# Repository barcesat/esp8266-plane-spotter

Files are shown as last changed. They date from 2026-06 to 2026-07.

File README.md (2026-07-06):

# ✈️ ESP8266 Plane Spotter

A desktop gadget with a **tactical / military-style** interface that shows the
**aircraft currently flying closest to your home** on a 0.96" OLED, plus live
weather, an NTP clock and a bunch of nerdy stats. Live ADS-B data comes from
the [OpenSky Network](https://opensky-network.org/) API; weather from
[Open-Meteo](https://open-meteo.com/); routes/airlines from
[hexdb.io](https://hexdb.io/). 3D-printable desktop case included in
[`hardware/`](hardware/).

Default home location is the **centre of Pinerolo (TO), Italy** — change it in
`config.h` to point at your own roof.

<p align="center">
  Plane Spotter desktop gadget showing the radar screen
</p>

<p align="center"><em>The finished gadget in its 3D-printed case, showing the RADAR screen.</em></p>

---

## What it shows

Every screen has a tactical header: title + page index on the left, a live NTP
clock on the right. It cycles through five screens every 7 seconds:

1. **TARGET** — nearest aircraft: callsign, a type icon, distance + compass
   bearing, altitude (m and flight level), a heading arrow, ground speed and a
   vertical altitude gauge.
2. **INTEL** — callsign, **airline**, **departure → arrival** route and an
   **ETA** estimate (looked up from hexdb.io), plus ICAO24 and heading.
3. **RADAR** — North-up PPI: home at the centre, range rings (outer = 120 km),
   a rotating sweep and a blip per aircraft. Blips are **dead-reckoned** from
   track + speed so they creep in real time between refreshes, with radar
   **persistence** (bright as the sweep passes, then a faint dot). The nearest
   is boxed; a tick marks the wall direction. Side panel: type, callsign, RNG,
   BRG, contact count.
4. **WX** — current weather (temperature, condition icon, humidity, wind) and a
   minimal next-hours forecast strip.
5. **SYSTEM** — big `HH:MM:SS` clock with live milliseconds, date, uptime,
   target count, WiFi signal bars, free RAM and request counters.

The **type icon** uses the OpenSky emitter category (`extended=1`) when present;
since that is often unset, the firmware otherwise estimates the type from
altitude + speed and flags it with a leading `~`.

Aircraft data refreshes every 60 s, weather every 10 min (both configurable —
see the rate-limit note below).

---

## Hardware

| Part | Notes |
|---|---|
| ESP8266 board | NodeMCU v2/v3, Wemos D1 mini, or similar |
| 0.96" OLED, **SSD1306** | either the 7-pin **4-wire SPI** module (`GND VCC SCK SDA RES DC CS`) or the 4-pin **I2C** module (`GND VCC SCL SDA`) |

### Wiring

Both SSD1306 module types are supported — set `OLED_USE_I2C` in `config.h` to
match yours (`false` = SPI, `true` = I2C).

**4-wire SPI module** (`OLED_USE_I2C false`): hardware SPI is used, so `SCK`
and `SDA` are fixed; the other three pins are configurable in `config.h`.

| OLED pin | ESP8266 (NodeMCU label / GPIO) | Role |
|---|---|---|
| GND | GND | Ground |
| VCC | 3V3 | Power |
| SCK | **D5 / GPIO14** | HW SPI clock (fixed) |
| SDA | **D7 / GPIO13** | HW SPI data / MOSI (fixed) |
| RES | D0 / GPIO16 | Reset |
| DC  | D2 / GPIO4  | Data/Command |
| CS  | D1 / GPIO5  | Chip select |

**I2C module** (`OLED_USE_I2C true`): hardware I2C on the ESP8266's standard
I2C pins; both are configurable in `config.h`.

| OLED pin | ESP8266 (NodeMCU label / GPIO) | Role |
|---|---|---|
| GND | GND | Ground |
| VCC | 3V3 | Power |
| SCL | **D1 / GPIO5** | I2C clock |
| SDA | **D2 / GPIO4** | I2C data |

> The default pins avoid the ESP8266 boot-strapping pins (GPIO0/2/15), so the
> board flashes and boots reliably. Most I2C SSD1306 modules use address
> `0x3C` (U8g2's default); if yours is `0x3D`, add
> `u8g2.setI2CAddress(0x3D * 2);` before `u8g2.begin()`.

**Wiring Schema**
```
        ESP8266 (NodeMCU)                OLED SSD1306 SPI
      ┌───────────────────┐            ┌──────────────────┐
      │ 3V3 ──────────────┼────────────┤ VCC              │
      │ GND ──────────────┼────────────┤ GND              │
      │ D5/GPIO14 ────────┼────────────┤ SCK              │
      │ D7/GPIO13 ────────┼────────────┤ SDA (MOSI)       │
      │ D0/GPIO16 ────────┼────────────┤ RES              │
      │ D2/GPIO4  ────────┼────────────┤ DC               │
      │ D1/GPIO5  ────────┼────────────┤ CS               │
      └───────────────────┘            └──────────────────┘

        ESP8266 (NodeMCU)                OLED SSD1306 I2C
      ┌───────────────────┐            ┌──────────────────┐
      │ 3V3 ──────────────┼────────────┤ VCC              │
      │ GND ──────────────┼────────────┤ GND              │
      │ D1/GPIO5  ────────┼────────────┤ SCL              │
      │ D2/GPIO4  ────────┼────────────┤ SDA              │
      └───────────────────┘            └──────────────────┘
```

### 3D-printed case

A simple two-part desktop case lives in [`hardware/`](hardware/):

| File | Part |
|---|---|
| [`hardware/Radar1.stl`](hardware/Radar1.stl) | Case part 1 |
| [`hardware/radar2.stl`](hardware/radar2.stl) | Case part 2 |

<p align="center">
  CAD render of the 3D-printed case
</p>

Print both, slot the board + OLED inside, and stand it on your desk. It is
designed to hang on a wall facing a known compass heading — set that heading in
`WALL_HEADING_DEG` so the radar's wall tick lines up.

---

## Build & flash

### Option A — Arduino IDE

1. Install the **ESP8266 board package** (Boards Manager → "esp8266").
2. Install libraries via **Library Manager**:
   - `U8g2` by olikraus
   - `ArduinoJson` by Benoit Blanchon (v7.x)
3. Copy `firmware/plane_spotter/config.example.h` → `config.h` and fill in your
   WiFi credentials (and your coordinates, if not Pinerolo).
4. Open `firmware/plane_spotter/plane_spotter.ino`, select your board, and
   upload.

### Option B — PlatformIO

```bash
cd firmware
# copy and edit the config first:
cp plane_spotter/config.example.h plane_spotter/config.h
pio run -t upload
pio device monitor
```

`platformio.ini` already pins the board, libraries, and 115200 monitor speed.

---

## Configuration

All settings live in `config.h` (git-ignored so your WiFi password stays
private). Key options:

| Define | Meaning |
|---|---|
| `WIFI_SSID` / `WIFI_PASS` | Your network |
| `OLED_USE_I2C` | Display module type: `false` = 4-wire SPI (7-pin), `true` = I2C (4-pin) |
| `HOME_LAT` / `HOME_LON` | Your home coordinates (default: Pinerolo) |
| `SEARCH_RADIUS_DEG` | Half-size of the sky box to query (~1.0° ≈ 111 km) |
| `UPDATE_INTERVAL_MS` | Poll period for OpenSky |
| `INCLUDE_ON_GROUND` | Include parked/taxiing aircraft; set `false` near airports |
| `WALL_HEADING_DEG` | Compass heading the wall/device faces (used by the radar wall tick) |
| `TIMEZONE` | POSIX timezone string for the NTP clock (default: Europe/Rome) |
| `WEATHER_INTERVAL_MS` | Weather refresh period (default: 10 min) |
| `OPENSKY_CLIENT_ID` / `OPENSKY_CLIENT_SECRET` | Optional OpenSky OAuth2 client for a much bigger budget |

### Data sources

| What | Service | Key needed |
|---|---|---|
| Aircraft (ADS-B) | OpenSky Network | optional (OAuth2 client → bigger quota) |
| Weather + forecast | Open-Meteo | no |
| Airline / route / ETA | hexdb.io | no |
| Clock | NTP (`pool.ntp.org`) | no |

> Route/ETA come from a community database, so they aren't available for every
> flight — `INTEL` shows `unknown` / `ETA --` when a route isn't found.

---

## Notes on the OpenSky API

- Anonymous access has a **small daily request budget (~400 calls)**, shared
  per public IP. Polling every 60 s is ~1440 calls/day, so anonymously you
  *will* hit `HTTP 429 Too many requests` and the display freezes on the last
  data (the firmware keeps showing the last known aircraft when rate-limited).
- **Recommended: use an OpenSky account.** Create one, go to *Account → API
  clients*, create a client, and put the `clientId`/`clientSecret` into
  `OPENSKY_CLIENT_ID`/`OPENSKY_CLIENT_SECRET`. The firmware then does the OAuth2
  `client_credentials` flow (token from `auth.opensky-network.org`, sent as a
  `Bearer` header, auto-refreshed) and gets a far larger quota — 60 s polling
  works comfortably. Anonymous (no client) still works if you raise
  `UPDATE_INTERVAL_MS` to ~300000 (5 min).
- **Aircraft-type icons:** OpenSky's emitter category (state index 17, via
  `extended=1`) is frequently `0` (unknown) in practice, so when it is missing
  the firmware estimates the type from altitude + speed and flags it with a
  leading `~` (e.g. `~Small`). Real category data, when present, is used as-is.
- Coverage is community ADS-B, so very low / very local traffic may not always
  appear. A larger `SEARCH_RADIUS_DEG` finds more planes but uses more RAM to
  parse (the ESP8266 only has ~40 KB free heap, so don't go wild).
- TLS certificate validation is skipped (`setInsecure()`) to keep memory low;
  fine for read-only public data.

---

## License

MIT — see [LICENSE](LICENSE).

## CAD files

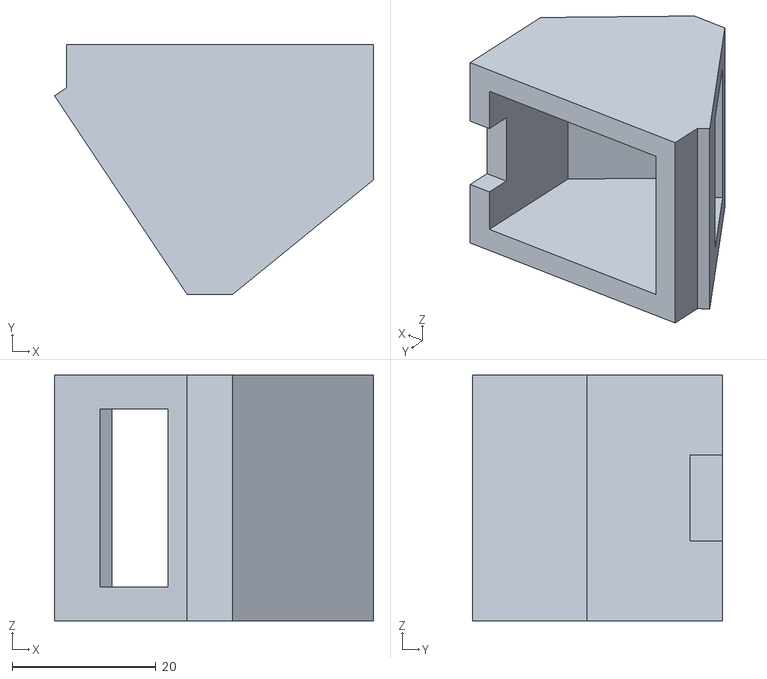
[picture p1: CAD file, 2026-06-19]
hardware/Radar1.stl
44.4 x 34.7 x 34.2

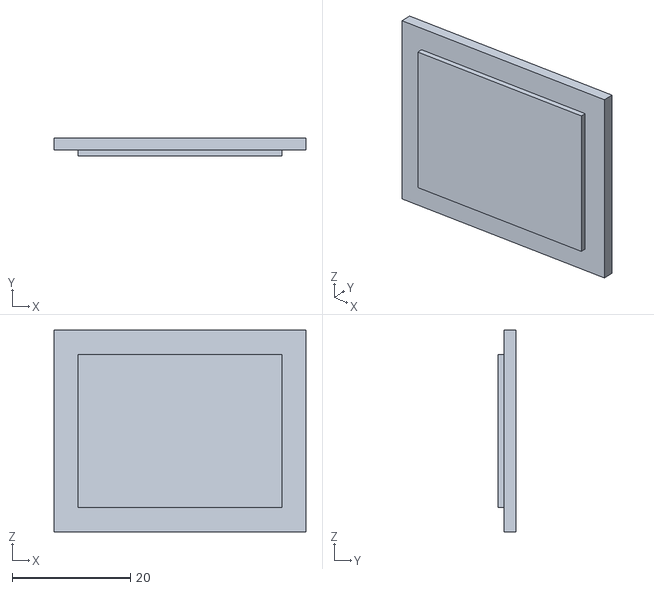
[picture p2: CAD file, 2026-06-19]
hardware/radar2.stl
42.7 x 3.00 x 34.2

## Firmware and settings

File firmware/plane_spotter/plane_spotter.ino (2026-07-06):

/*
 * ESP8266 Plane Spotter
 * --------------------------------------------------------------------------
 * Shows the aircraft currently flying closest to your home on a 0.96" SSD1306
 * OLED, plus a bunch of nerdy statistics. Live ADS-B data is pulled from
 * the free OpenSky Network REST API.
 *
 * Board   : any ESP8266 (NodeMCU v2/v3, Wemos D1 mini, ...)
 * Display : 0.96" OLED, SSD1306 128x64, either
 *           - 4-wire SPI (7 pins: GND, VCC, SCK, SDA, RES, DC, CS), or
 *           - I2C (4 pins: GND, VCC, SCL, SDA)
 *           Pick with OLED_USE_I2C in config.h.
 *
 * Wiring (defaults, see README for the full tables):
 *   SPI OLED  ESP8266                    I2C OLED  ESP8266
 *   GND  -->  GND                        GND  -->  GND
 *   VCC  -->  3V3                        VCC  -->  3V3
 *   SCK  -->  D5 / GPIO14 (HW, fixed)    SCL  -->  D1 / GPIO5
 *   SDA  -->  D7 / GPIO13 (HW, fixed)    SDA  -->  D2 / GPIO4
 *   RES  -->  D0 / GPIO16
 *   DC   -->  D2 / GPIO4
 *   CS   -->  D1 / GPIO5
 *
 * Libraries (install from the Arduino Library Manager):
 *   - U8g2        by olikraus
 *   - ArduinoJson by Benoit Blanchon (v6.x)
 *
 * Copy config.example.h to config.h and fill in your details before flashing.
 */

#include <ESP8266WiFi.h>
#include <WiFiClientSecure.h>
#include <ESP8266HTTPClient.h>
#include <ArduinoJson.h>
#include <U8g2lib.h>
#include <math.h>
#include <time.h>
#include <sys/time.h>

#include "config.h"

#ifndef INCLUDE_ON_GROUND
#define INCLUDE_ON_GROUND true
#endif

// ---------------------------------------------------------------------------
// Display: SSD1306 128x64, 4-wire hardware SPI or hardware I2C, selected by
// OLED_USE_I2C in config.h.
// SPI: HW SPI uses the fixed ESP8266 pins SCLK=GPIO14 (D5) and MOSI=GPIO13
//   (D7); only CS / DC / RESET are configurable.
// I2C: SCL/SDA pins come from config.h (defaults: SCL=GPIO5/D1, SDA=GPIO4/D2,
//   the ESP8266 standard I2C pins). Most modules answer at address 0x3C,
//   U8g2's default; if yours is 0x3D, add u8g2.setI2CAddress(0x3D * 2)
//   before begin().
// ---------------------------------------------------------------------------
#ifndef OLED_USE_I2C
#define OLED_USE_I2C false   // config.h files from before this switch are SPI
#endif

#if OLED_USE_I2C
U8G2_SSD1306_128X64_NONAME_F_HW_I2C u8g2(U8G2_R0, /* reset=*/ U8X8_PIN_NONE,
                                         /* clock=*/ PIN_OLED_SCL,
                                         /* data=*/  PIN_OLED_SDA);
#else
U8G2_SSD1306_128X64_NONAME_F_4W_HW_SPI u8g2(U8G2_R0, PIN_OLED_CS, PIN_OLED_DC,
                                            PIN_OLED_RST);
#endif

// ---------------------------------------------------------------------------
// Data model
// ---------------------------------------------------------------------------
struct Aircraft {
  char   icao24[8];
  char   callsign[10];
  char   country[24];
  double lat;
  double lon;
  float  altitudeM;   // geometric/barometric altitude in metres
  float  velocityMs;  // ground speed in m/s
  float  trackDeg;    // true track over ground (0 = north)
  float  vrateMs;     // vertical rate in m/s (+climb / -descent)
  bool   onGround;
  int    category;    // OpenSky emitter category (state index 17, 0 = unknown)
  double distanceKm;  // great-circle distance from home
  double bearingDeg;  // bearing from home to aircraft
  bool   valid;
};

Aircraft nearest;

// Per-aircraft state for the radar, including enough to dead-reckon (estimate)
// the position between data refreshes so the blips creep in real time.
struct Blip { double lat; double lon; float track; float speedMs; };
const uint8_t MAX_BLIPS = 20;
Blip     blips[MAX_BLIPS];
uint8_t  blipCount  = 0;
uint32_t lastDataMs = 0;   // millis() of the last successful aircraft fetch

// OpenSky OAuth2 bearer token (when client credentials are configured).
String   accessToken;
uint32_t tokenExpiryMs = 0;

// Current weather (from Open-Meteo).
struct Weather {
  float tempC;
  float windKmh;
  int   humidity;
  int   code;      // WMO weather code
  bool  valid = false;
} weather;
uint32_t lastWeatherPoll = 0;

// Short hourly forecast (a few hours ahead).
struct Fcast { int hour; float tempC; int code; };
const uint8_t FC_N = 3;
Fcast   fcast[FC_N];
uint8_t fcCount = 0;

// Route / airline / ETA for the current nearest aircraft (from hexdb.io).
struct RouteInfo {
  char   callsign[10];   // which callsign this data is for
  char   airline[18];
  char   dep[6];
  char   arr[6];
  bool   haveRoute;
  bool   haveArrPos;
  double arrLat, arrLon;
} routeInfo;

// Runtime statistics (the nerdy bit)
struct Stats {
  uint32_t requestsOk   = 0;
  uint32_t requestsFail = 0;
  uint16_t inView       = 0;   // aircraft inside the search box on last poll
  uint16_t maxInView    = 0;   // session record
  double   closestEver  = 1e9; // closest distance seen this session (km)
  uint32_t lastUpdateMs = 0;
} stats;

uint8_t  screen           = 0;         // which screen is showing
uint32_t lastScreenSwap   = 0;
uint32_t lastPoll         = 0;
bool     firstFetchDone   = false;
bool     firstWeatherDone = false;

const uint8_t  NUM_SCREENS    = 5;
const uint32_t SCREEN_SWAP_MS = 7000;

// ---------------------------------------------------------------------------
// Geo helpers
// ---------------------------------------------------------------------------
static double deg2rad(double d) { return d * (PI / 180.0); }
static double rad2deg(double r) { return r * (180.0 / PI); }

// Great-circle distance (Haversine) in kilometres.
double haversineKm(double lat1, double lon1, double lat2, double lon2) {
  const double R = 6371.0;
  double dLat = deg2rad(lat2 - lat1);
  double dLon = deg2rad(lon2 - lon1);
  double a = sin(dLat / 2) * sin(dLat / 2) +
             cos(deg2rad(lat1)) * cos(deg2rad(lat2)) *
             sin(dLon / 2) * sin(dLon / 2);
  return R * 2 * atan2(sqrt(a), sqrt(1 - a));
}

// Initial bearing from point 1 to point 2, degrees 0..360.
double bearingDeg(double lat1, double lon1, double lat2, double lon2) {
  double y = sin(deg2rad(lon2 - lon1)) * cos(deg2rad(lat2));
  double x = cos(deg2rad(lat1)) * sin(deg2rad(lat2)) -
             sin(deg2rad(lat1)) * cos(deg2rad(lat2)) * cos(deg2rad(lon2 - lon1));
  double b = rad2deg(atan2(y, x));
  return fmod(b + 360.0, 360.0);
}

const char* compass(double bearing) {
  static const char* dirs[] = {"N", "NE", "E", "SE", "S", "SW", "W", "NW"};
  return dirs[(int)((bearing + 22.5) / 45.0) % 8];
}

// ---------------------------------------------------------------------------
// WiFi
// ---------------------------------------------------------------------------
void connectWiFi() {
  WiFi.mode(WIFI_STA);
  WiFi.begin(WIFI_SSID, WIFI_PASS);

  uint8_t dots = 0;
  while (WiFi.status() != WL_CONNECTED) {
    u8g2.clearBuffer();
    u8g2.setFont(u8g2_font_6x12_tr);
    u8g2.drawStr(0, 12, "Plane Spotter");
    u8g2.drawStr(0, 30, "Connecting WiFi");
    u8g2.setCursor(0, 46);
    u8g2.print(WIFI_SSID);
    u8g2.setCursor(0, 62);
    for (uint8_t i = 0; i < (dots % 16) + 1; i++) u8g2.print('.');
    u8g2.sendBuffer();
    delay(400);
    dots++;
  }
  Serial.printf("\n[wifi] connected SSID=%s IP=%s RSSI=%d\n",
                WIFI_SSID, WiFi.localIP().toString().c_str(), WiFi.RSSI());
}

// ---------------------------------------------------------------------------
// OpenSky fetch
// ---------------------------------------------------------------------------
String buildUrl() {
  double lamin = HOME_LAT - SEARCH_RADIUS_DEG;
  double lamax = HOME_LAT + SEARCH_RADIUS_DEG;
  double lomin = HOME_LON - SEARCH_RADIUS_DEG;
  double lomax = HOME_LON + SEARCH_RADIUS_DEG;

  String url = "https://opensky-network.org/api/states/all?";
  url += "lamin=" + String(lamin, 4);
  url += "&lomin=" + String(lomin, 4);
  url += "&lamax=" + String(lamax, 4);
  url += "&lomax=" + String(lomax, 4);
  url += "&extended=1";   // include the aircraft category (state index 17)
  return url;
}

// Whether OAuth2 client credentials are configured.
bool oauthConfigured() { return strlen(OPENSKY_CLIENT_ID) > 0; }

// Request a fresh OAuth2 access token (client_credentials grant). Returns true
// on success and stores it in `accessToken` with an expiry a minute early.
bool fetchToken() {
  WiFiClientSecure client;
  client.setInsecure();
  client.setBufferSizes(16384, 512);

  HTTPClient https;
  https.setReuse(false);
  if (!https.begin(client,
        "https://auth.opensky-network.org/auth/realms/opensky-network/protocol/openid-connect/token")) {
    Serial.println("[auth] begin() failed");
    return false;
  }
  https.addHeader("Content-Type", "application/x-www-form-urlencoded");
  String body = "grant_type=client_credentials&client_id=";
  body += OPENSKY_CLIENT_ID;
  body += "&client_secret=";
  body += OPENSKY_CLIENT_SECRET;

  int code = https.POST(body);
  Serial.printf("[auth] token HTTP %d\n", code);
  if (code != HTTP_CODE_OK) { https.end(); return false; }

  String payload = https.getString();
  https.end();

  JsonDocument filter;
  filter["access_token"] = true;
  filter["expires_in"]   = true;
  JsonDocument doc;
  if (deserializeJson(doc, payload, DeserializationOption::Filter(filter))) {
    Serial.println("[auth] token JSON parse failed");
    return false;
  }
  const char* tok = doc["access_token"] | "";
  if (!tok[0]) return false;

  accessToken = tok;
  int exp = doc["expires_in"] | 1800;
  tokenExpiryMs = millis() + (uint32_t)(exp > 120 ? exp - 60 : exp) * 1000UL;
  Serial.printf("[auth] token ok (len=%u, expires in %ds)\n", accessToken.length(), exp);
  return true;
}

// Pulls aircraft states, keeps the nearest one. Returns true on success.
bool fetchAircraft() {
  // Refresh the OAuth2 token first, before the data client exists, so we never
  // hold two 16 KB TLS buffers at once.
  if (oauthConfigured() &&
      (accessToken.length() == 0 || (int32_t)(millis() - tokenExpiryMs) >= 0)) {
    fetchToken();
  }

  WiFiClientSecure client;
  client.setInsecure();                 // skip cert validation (read-only data)
  // Do NOT shrink the RX buffer below the default 16 KB: OpenSky does not
  // negotiate a smaller TLS fragment (no MFLN), so a small RX buffer makes the
  // TLS handshake fail and every fetch silently returns "no aircraft".
  client.setBufferSizes(16384, 512);

  HTTPClient https;
  https.setReuse(false);
  String url = buildUrl();
  Serial.printf("[fetch] heap=%u GET %s\n", ESP.getFreeHeap(), url.c_str());
  if (!https.begin(client, url)) {
    Serial.println("[fetch] https.begin() failed");
    stats.requestsFail++;
    return false;
  }

  if (oauthConfigured() && accessToken.length() > 0) {
    https.addHeader("Authorization", "Bearer " + accessToken);
  }

  int code = https.GET();
  Serial.printf("[fetch] HTTP %d\n", code);
  if (code != HTTP_CODE_OK) {
    if (code == HTTP_CODE_UNAUTHORIZED) accessToken = "";  // force token refresh
    https.end();
    stats.requestsFail++;
    return false;
  }

  // Filter: keep only the fields we actually use from every state vector.
  // OpenSky state indices: 0 icao24, 1 callsign, 2 origin_country,
  // 5 longitude, 6 latitude, 7 baro_altitude, 8 on_ground, 9 velocity,
  // 10 true_track, 11 vertical_rate, 13 geo_altitude.
  JsonDocument filter;
  JsonArray el = filter["states"].to<JsonArray>().add<JsonArray>();
  for (int i = 0; i <= 17; i++) el[i] = false;
  el[0] = el[1] = el[2] = el[5] = el[6] = true;
  el[7] = el[8] = el[9] = el[10] = el[11] = el[13] = el[17] = true;

  // OpenSky replies with Transfer-Encoding: chunked. getStream() would hand the
  // raw chunked bytes (hex length markers) to the parser and yield nothing, so
  // we use getString(), which de-chunks the body before we parse it.
  String payload = https.getString();
  https.end();
  Serial.printf("[fetch] payload=%u bytes\n", payload.length());

  JsonDocument doc;
  DeserializationError err = deserializeJson(
      doc, payload, DeserializationOption::Filter(filter));

  if (err) {
    Serial.printf("[fetch] JSON error: %s\n", err.c_str());
    stats.requestsFail++;
    return false;
  }

  JsonArray states = doc["states"].as<JsonArray>();
  Aircraft best;
  best.valid      = false;
  best.distanceKm = 1e9;
  uint16_t count  = 0;
  blipCount = 0;

  for (JsonArray s : states) {
    if (s.isNull() || s[5].isNull() || s[6].isNull()) continue;
    bool onGround = s[8] | false;
    if (onGround && !INCLUDE_ON_GROUND) continue;

    double lon = s[5].as<double>();
    double lat = s[6].as<double>();
    double d   = haversineKm(HOME_LAT, HOME_LON, lat, lon);
    double brg = bearingDeg(HOME_LAT, HOME_LON, lat, lon);
    count++;

    if (blipCount < MAX_BLIPS) {
      blips[blipCount].lat     = lat;
      blips[blipCount].lon     = lon;
      blips[blipCount].track   = s[10] | 0.0f;
      blips[blipCount].speedMs = onGround ? 0.0f : (s[9] | 0.0f);
      blipCount++;
    }

    if (d < best.distanceKm) {
      best.distanceKm = d;
      best.lat        = lat;
      best.lon        = lon;
      best.bearingDeg = brg;
      best.onGround   = onGround;
      best.category   = s[17] | 0;

      // geo altitude (13) preferred, fall back to barometric (7)
      best.altitudeM  = s[13].isNull() ? (s[7] | 0.0f) : s[13].as<float>();
      best.velocityMs = s[9]  | 0.0f;
      best.trackDeg   = s[10] | 0.0f;
      best.vrateMs    = s[11] | 0.0f;

      const char* cs = s[1] | "";
      strncpy(best.callsign, cs, sizeof(best.callsign) - 1);
      best.callsign[sizeof(best.callsign) - 1] = '\0';
      // trim trailing spaces OpenSky pads callsigns with
      for (int i = strlen(best.callsign) - 1; i >= 0 && best.callsign[i] == ' '; i--)
        best.callsign[i] = '\0';
      if (best.callsign[0] == '\0') strcpy(best.callsign, "(no id)");

      const char* ic = s[0] | "";
      strncpy(best.icao24, ic, sizeof(best.icao24) - 1);
      best.icao24[sizeof(best.icao24) - 1] = '\0';

      const char* co = s[2] | "?";
      strncpy(best.country, co, sizeof(best.country) - 1);
      best.country[sizeof(best.country) - 1] = '\0';

      best.valid = true;
    }
  }

  stats.inView       = count;
  if (count > stats.maxInView) stats.maxInView = count;
  stats.requestsOk++;
  stats.lastUpdateMs = millis();
  lastDataMs         = millis();

  nearest = best;
  if (nearest.valid && nearest.distanceKm < stats.closestEver)
    stats.closestEver = nearest.distanceKm;

  Serial.printf("[fetch] inView=%u blips=%u nearest=%s cat=%d dist=%.1fkm valid=%d heap=%u\n",
                count, blipCount, nearest.valid ? nearest.callsign : "-",
                nearest.valid ? nearest.category : -1,
                nearest.valid ? nearest.distanceKm : 0.0, nearest.valid,
                ESP.getFreeHeap());
  return true;
}

// ---------------------------------------------------------------------------
// Weather (Open-Meteo, no API key required)
// ---------------------------------------------------------------------------
bool fetchWeather() {
  WiFiClientSecure client;
  client.setInsecure();
  client.setBufferSizes(16384, 512);

  HTTPClient https;
  https.setReuse(false);
  String url = "https://api.open-meteo.com/v1/forecast?latitude=";
  url += String(HOME_LAT, 4);
  url += "&longitude=" + String(HOME_LON, 4);
  url += "&current=temperature_2m,relative_humidity_2m,weather_code,wind_speed_10m";
  url += "&hourly=temperature_2m,weather_code&forecast_hours=8&timezone=auto";
  if (!https.begin(client, url)) return false;

  int code = https.GET();
  Serial.printf("[wx] HTTP %d\n", code);
  if (code != HTTP_CODE_OK) { https.end(); return false; }
  String payload = https.getString();
  https.end();

  JsonDocument filter;
  filter["current"] = true;
  filter["hourly"]  = true;
  JsonDocument doc;
  if (deserializeJson(doc, payload, DeserializationOption::Filter(filter))) return false;
  JsonObject c = doc["current"];
  if (c.isNull()) return false;

  weather.tempC    = c["temperature_2m"]       | 0.0f;
  weather.humidity = c["relative_humidity_2m"] | 0;
  weather.code     = c["weather_code"]         | 0;
  weather.windKmh  = c["wind_speed_10m"]       | 0.0f;
  weather.valid    = true;

  // short forecast: a few hours ahead (index 0 of forecast_hours == now)
  JsonArray ht = doc["hourly"]["temperature_2m"].as<JsonArray>();
  JsonArray hc = doc["hourly"]["weather_code"].as<JsonArray>();
  int nowH = -1;
  if (timeReady()) {
    time_t t = time(nullptr);
    struct tm lt;
    localtime_r(&t, &lt);
    nowH = lt.tm_hour;
  }
  const int offs[FC_N] = {2, 4, 6};
  fcCount = 0;
  for (uint8_t k = 0; k < FC_N; k++) {
    int idx = offs[k];
    if ((int)ht.size() > idx) {
      fcast[fcCount].tempC = ht[idx] | 0.0f;
      fcast[fcCount].code  = hc[idx] | 0;
      fcast[fcCount].hour  = (nowH < 0) ? -1 : ((nowH + idx) % 24);
      fcCount++;
    }
  }

  Serial.printf("[wx] %.1fC hum=%d%% wind=%.0f code=%d fc=%u\n",
                weather.tempC, weather.humidity, weather.windKmh, weather.code, fcCount);
  return true;
}

// Short label and icon-kind (0 sun,1 part,2 cloud,3 fog,4 rain,5 snow,6 storm)
// for a WMO weather code.
const char* wxText(int code) {
  if (code == 0)                  return "CLEAR";
  if (code <= 2)                  return "PARTLY";
  if (code == 3)                  return "OVERCAST";
  if (code == 45 || code == 48)   return "FOG";
  if (code >= 51 && code <= 57)   return "DRIZZLE";
  if (code >= 61 && code <= 67)   return "RAIN";
  if (code >= 71 && code <= 77)   return "SNOW";
  if (code >= 80 && code <= 82)   return "SHOWERS";
  if (code >= 85 && code <= 86)   return "SNOW";
  if (code >= 95)                 return "STORM";
  return "WX";
}
int wxKind(int code) {
  if (code == 0)                                       return 0;
  if (code <= 2)                                       return 1;
  if (code == 3)                                       return 2;
  if (code == 45 || code == 48)                        return 3;
  if ((code >= 51 && code <= 67) || (code >= 80 && code <= 82)) return 4;
  if ((code >= 71 && code <= 77) || (code >= 85 && code <= 86)) return 5;
  if (code >= 95)                                      return 6;
  return 2;
}

// ---------------------------------------------------------------------------
// Route / airline / ETA (hexdb.io, free, no key)
// ---------------------------------------------------------------------------
// Generic HTTPS GET into a String. Returns true on HTTP 200.
bool httpGetString(const String& url, String& out) {
  WiFiClientSecure client;
  client.setInsecure();
  client.setBufferSizes(16384, 512);
  HTTPClient https;
  https.setReuse(false);
  if (!https.begin(client, url)) return false;
  int code = https.GET();
  if (code != HTTP_CODE_OK) { https.end(); return false; }
  out = https.getString();
  https.end();
  return true;
}

// Offline ICAO airline-designator table (first 3 letters of the callsign).
struct Airline { const char* code; const char* name; };
const Airline AIRLINES[] = {
  {"RYR","Ryanair"},   {"EJU","easyJet EU"},{"EZY","easyJet"},   {"WZZ","Wizz Air"},
  {"VOE","Volotea"},   {"VLG","Vueling"},   {"ITY","ITA Airways"},{"AZA","Alitalia"},
  {"AFR","Air France"},{"DLH","Lufthansa"}, {"BAW","British AW"},{"KLM","KLM"},
  {"IBE","Iberia"},    {"SWR","SWISS"},     {"AUA","Austrian"},  {"TAP","TAP Air"},
  {"SAS","SAS"},       {"FIN","Finnair"},   {"LOT","LOT Polish"},{"THY","Turkish"},
  {"UAE","Emirates"},  {"QTR","Qatar"},     {"ETD","Etihad"},    {"ELY","El Al"},
  {"AEE","Aegean"},    {"TRA","Transavia"}, {"NAX","Norwegian"}, {"EWG","Eurowings"},
  {"BEL","Brussels"},  {"TVF","Transavia"}, {"ENT","Enter Air"}, {"DAL","Delta"},
  {"UAL","United"},    {"AAL","American"},  {"ACA","Air Canada"},{"UPS","UPS"},
  {"FDX","FedEx"},     {"BCS","DHL Air"},   {"MSR","EgyptAir"},  {"RAM","Royal Air Maroc"},
  {"AZU","Azul"},      {"QFA","Qantas"},    {"SIA","Singapore"}, {"NJE","NetJets"},
  {"EXS","Jet2"},      {"WUK","Wizz UK"},   {"NSZ","Norse"},     {"MMZ","euroAtlantic"},
};

const char* airlineName(const char* callsign) {
  static char fb[4];
  if (!callsign || strlen(callsign) < 3) return "GA / Private";
  char p[4] = { (char)toupper(callsign[0]), (char)toupper(callsign[1]),
                (char)toupper(callsign[2]), 0 };
  for (auto& a : AIRLINES) if (strcmp(a.code, p) == 0) return a.name;
  strcpy(fb, p);
  return fb;   // unknown -> show the 3-letter operator code
}
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
void loop() {
  uint32_t now = millis();

  if (!firstFetchDone || now - lastPoll >= UPDATE_INTERVAL_MS) {
    if (WiFi.status() != WL_CONNECTED) connectWiFi();
    fetchAircraft();
    if (nearest.valid && strcmp(routeInfo.callsign, nearest.callsign) != 0)
      fetchRoute(nearest.callsign);
    lastPoll = now;
    firstFetchDone = true;
  }

  if (!firstWeatherDone || now - lastWeatherPoll >= WEATHER_INTERVAL_MS) {
    if (WiFi.status() == WL_CONNECTED) fetchWeather();
    lastWeatherPoll = now;
    firstWeatherDone = true;
  }

  if (now - lastScreenSwap >= SCREEN_SWAP_MS) {
    screen = (screen + 1) % NUM_SCREENS;
    lastScreenSwap = now;
  }

  render();
  delay(33);   // ~30 fps: smooth radar sweep + fast-ticking clock
}

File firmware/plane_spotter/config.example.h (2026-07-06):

/*
 * Configuration template.
 *
 *   1. Copy this file to "config.h" (same folder).
 *   2. Fill in your WiFi credentials and home coordinates.
 *   3. config.h is git-ignored so your secrets never get committed.
 */
#pragma once

// ---- WiFi ----------------------------------------------------------------
#define WIFI_SSID  "YOUR_WIFI_NAME"
#define WIFI_PASS  "YOUR_WIFI_PASSWORD"

// ---- Home location -------------------------------------------------------
// Default: centre of Pinerolo (TO), Italy.
#define HOME_LAT   44.8848
#define HOME_LON   7.3306

// Half-size of the search box in degrees (~1.0 deg latitude is ~111 km).
// Smaller = less data to parse on the ESP8266, larger = wider sky coverage
// (but more RAM used; on a quiet sky raise it, if it reboots lower it).
#define SEARCH_RADIUS_DEG  1.0

// How often to poll OpenSky, in milliseconds. Anonymous access has a small
// daily budget (~400 calls): 60 s already exceeds it over 24 h, so for
// continuous use set OPENSKY_USER/PASS below (a free account = far more calls).
#define UPDATE_INTERVAL_MS  60000

// Include aircraft that OpenSky reports as on-ground (parked/taxiing).
// Set to false if you live near an airport and do not want parked planes
// to win "nearest aircraft" or appear as radar contacts.
#define INCLUDE_ON_GROUND  false

// Compass heading (deg, 0=N 90=E 180=S 270=W) that the wall / device faces.
// Used by the radar screen to mark the wall direction.
#define WALL_HEADING_DEG  194

// POSIX timezone string for the NTP clock (default: Europe/Rome). See
// https://github.com/nayarsystems/posix_tz_db for other zones.
#define TIMEZONE  "CET-1CEST,M3.5.0,M10.5.0/3"

// How often to refresh weather from Open-Meteo (ms). 10 min is plenty.
#define WEATHER_INTERVAL_MS  600000

// ---- OpenSky OAuth2 client (optional) ------------------------------------
// Leave both empty for anonymous access (small ~400 calls/day budget). For a
// much larger quota, create a free account at https://opensky-network.org/,
// then Account -> API clients -> create a client, and paste the resulting
// clientId / clientSecret here. The firmware fetches an OAuth2 token and sends
// it as a Bearer header.
#define OPENSKY_CLIENT_ID      ""
#define OPENSKY_CLIENT_SECRET  ""

// ---- OLED display ----------------------------------------------------------
// Two SSD1306 128x64 module types are supported; pick yours:
//   false = 7-pin 4-wire SPI module (GND VCC SCK SDA RES DC CS)
//   true  = 4-pin I2C module        (GND VCC SCL SDA)
#define OLED_USE_I2C  false

// I2C pins (only used when OLED_USE_I2C is true). Defaults are the ESP8266
// standard I2C pins:
#define PIN_OLED_SCL  5    // D1
#define PIN_OLED_SDA  4    // D2

// SPI control pins (only used when OLED_USE_I2C is false). SCK -> GPIO14 (D5)
// and SDA/MOSI -> GPIO13 (D7) are fixed by HW SPI; these three are
// configurable:
#define PIN_OLED_RST  16   // D0
#define PIN_OLED_DC    4   // D2
#define PIN_OLED_CS    5   // D1

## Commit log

2026-06-18 Initial commit: ESP8266 Plane Spotter
    Shows the nearest aircraft to home on a 0.96-inch SSD1306 SPI OLED using live
    OpenSky Network ADS-B data, plus rotating nerd-stats screens.
2026-06-19 STL Files
    [Radar1.stl, radar2.stl]
2026-06-19 Organize STL case files into hardware/ and document everything
    - Move Radar1.stl / radar2.stl into hardware/.
    - Rewrite the README for the five tactical screens (TARGET/INTEL/RADAR/WX/
    SYSTEM), the weather + NTP clock + route/airline/ETA features, the data
    sources, and the 3D-printed case.
    [Radar1.stl, radar2.stl]
2026-07-04 Ignore aircraft reported on ground by default
    Add INCLUDE_ON_GROUND so users near airports can exclude parked or taxiing aircraft from the target selection, radar contacts, and live counters. The firmware remains backwards-compatible with older config.h files by preserving the previous include-on-ground behavior when the define is missing.
    Fixes #3
    [config.example.h, plane_spotter.ino]
2026-07-06 Switch display from 4-wire SPI to I2C SSD1306
    - Use U8g2 HW I2C constructor (SCL=D1/GPIO5, SDA=D2/GPIO4) at 400 kHz
    so the ~30 fps radar sweep stays smooth
    - Replace SPI pin defines with PIN_OLED_SCL / PIN_OLED_SDA in config
    - Lay out body content below row 16 so two-color (yellow/cyan) panels
    show the header in yellow and content fully in cyan
    - Bump ArduinoJson to v7 in platformio.ini (code already uses v7 API)
    - Update README wiring docs for the 4-pin I2C module
    [config.example.h, plane_spotter.ino]
2026-07-06 Support both SPI and I2C SSD1306 displays via config switch
    - New OLED_USE_I2C define in config.h selects the U8g2 constructor:
    false = 7-pin 4-wire HW SPI module (upstream default), true = 4-pin
    HW I2C module (400 kHz bus so the ~30 fps radar sweep stays smooth)
    - Defaults to SPI when the define is absent, so existing config.h
    files keep working unchanged
    - config.example.h documents the switch and both pin groups
    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
2026-07-06 moved the wiring schema up
